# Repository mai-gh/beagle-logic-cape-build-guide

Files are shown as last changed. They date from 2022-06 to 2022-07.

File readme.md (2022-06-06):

# beagle-logic-cape-build-guide

## TL;DR:

upload `beaglelogic_cape_v1-1-gerbers.zip` to https://dirtypcbs.com/store/pcbs

## The Dilemma:

I found out about this project a little late, but it seems like it could be very useful, even if some things are a bit outdated.

I need a logic analyzer and i found this: https://sigrok.org/wiki/BeagleLogic

there are a few problems though. the beaglebone blacks gpios are only 3.3v tolerant, so this "cape" was made to allowing analyzing 5v circuits.
this board is not sold anywhere. ok so we can order a pcb and the components and buid it right? well finding gerbers to send to a pcb fabricator was tricky, they are not in the beagle logic repository. https://github.com/abhishek-kakkar/BeagleLogic (commit f9dab91ac01472fdafd758277ec8a4526c6267f5) (Jul 5, 2020)

however there is kicad design files which can be used to generate new gerbers. I described my process of how generated the gerbers with kicad 5.1.10-4 in [KiCad-Gerber-DirtyPCBs.md](https://github.com/mai-gh/beagle-logic-cape-build-guide/blob/main/KiCad-Gerber-DirtyPCBs.md)

## Components:

info comes from here: https://docs.google.com/spreadsheets/d/12azxrOXTphC75ShBOmVUEJG1oJav0N1jhAYYi9JiIA4/edit#gid=0

|Reference|Type |Qty|DigiKey|Mouser|Extra|
|---|---|---|---|---|-----|
|C1 |1uF 0603 X7R |1  |[490-10734-1-ND](https://www.digikey.com/en/products/result?keywords=490-10734-1-ND) |81-GRM188R71C105KE5D |
|C2 |0.1uF 0603 |1  |[490-1524-1-ND](https://www.digikey.com/en/products/result?keywords=490-1524-1-ND) |81-GRM39X104K25 |
|U1 |BeagleBone Stackable Cape Headers |2  |[1528-1365-ND](https://www.digikey.com/en/products/result?keywords=1528-1365-ND) || https://www.adafruit.com/products/706|
|U2 |SN74LVCH16T245DGGR |1  |[296-19568-1-ND](https://www.digikey.com/en/products/result?keywords=296-19568-1-ND) |595-SN74LVCH16T245GR |
|P1 |14x2 (28pin) right angled 2.54mm male pin strip |1  |[S2112EC-14-ND](https://www.digikey.com/en/products/result?keywords=S2112EC-14-ND) |(suggest alternative part here)|
|Q1 |BSS138 |1  |[BSS138CT-ND](https://www.digikey.com/en/products/result?keywords=BSS138CT-ND) |9845330 |
|R1 |0603, 100K |1  |[311-100KHRCT-ND](https://www.digikey.com/en/products/result?keywords=311-100KHRCT-ND)  |603-RC0603FR-07100KL |
|R14 |0603, 1K |1  |[311-1.00KHRCT-ND](https://www.digikey.com/en/products/result?keywords=311-1.00KHRCT-ND) |603-RC0603FR-071KL |
|R15 |0402, 0R (solder bridge in practice) |0  |[311-0.0JRCT-ND](https://www.digikey.com/en/products/result?keywords=311-0.0JRCT-ND) |603-RC0402JR-070RL |
|R8 |0603, 0R (not populated unless 14 channels are required) |0  |[311-0.0HRCT-ND](https://www.digikey.com/en/products/result?keywords=311-0.0HRCT-ND) |603-RC0603FR-070RL |
|R9 |0603, 0R (not populated unless 14 channels are required)  

## Cheaper Sources:

this table is for the cheapest prices to build 10 capes

|Ref|Link|Order Qty|
|---|----|---|
|C1 | https://lcsc.com/product-detail/Multilayer-Ceramic-Capacitors-MLCC-SMD-SMT_Taiyo-Yuden-EMK107B7105KA-T_C92759.html | 50  |
|C2 | https://lcsc.com/product-detail/Multilayer-Ceramic-Capacitors-MLCC-SMD-SMT_CCTC-TCC0603X7R104K500CT_C282519.html | 100 |
|U1 | https://www.aliexpress.com/item/3256803448359946.html | 2X20P 20PCS & 2X3P 20PCS |
|U2 | https://lcsc.com/product-detail/Receivers-Transceivers_Texas-Instruments-SN74LVCH16T245DGGR_C352975.html | 10  |
|P1 | https://lcsc.com/product-detail/Pin-Headers_HCTL-PZ254-2-14-W-8-5_C2894994.html | 10  |
|Q1 | https://lcsc.com/product-detail/MOSFETs_UMW-Youtai-Semiconductor-Co-Ltd-BSS138_C347484.html | 10  |
|R1 | https://lcsc.com/product-detail/Chip-Resistor-Surface-Mount_Walsin-Tech-Corp-WR06X1003FTL_C132374.html | 100 | 
|R14| https://lcsc.com/product-detail/Chip-Resistor-Surface-Mount_YAGEO-RC0603FR-071KL_C22548.html | 100 |

### Total Costs:

( includes shipping )

|Site|Description|Price|
|----|---|-----|
|dirtypcbs | 10x pcbs | $31.95 |
|aliexpress| stackable cape headers | $13.52 |
|lcsc | all other components | $22.98 |

**Total: $68.45**

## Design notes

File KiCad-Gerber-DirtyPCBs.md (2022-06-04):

# KiCad-Gerber-DirtyPCBs

### Original Document: https://github.com/VojislavM/KiCad-Gerber-Wiki

In this guide I will be using `kicad 5.1.10-4`

Documentation how to generate Gerber files from KiCad for PCB manufacturing at [dirtypcbs][DIRTY_PCB_LINK]. 

On this link, you can find all information about [dirtypcbs info][DIRTY_PCB_ABOUT_LINK] PCB manufacturing. 

There are several things need to be done before sending files to manufacture PCBs. Files are generated with KiCad EDA tool, and these are the steps to send your files to [dirtypcbs][DIRTY_PCB_LINK] and get your boards as you want.

When board file is finished:

1. Set the origin: Go to **Place** -> **Drill and Place offset** and then set the origin near the bottom left corner of the board. for this project i set the grid size to 1.0mm and chose:
- x: 114
- y: 130

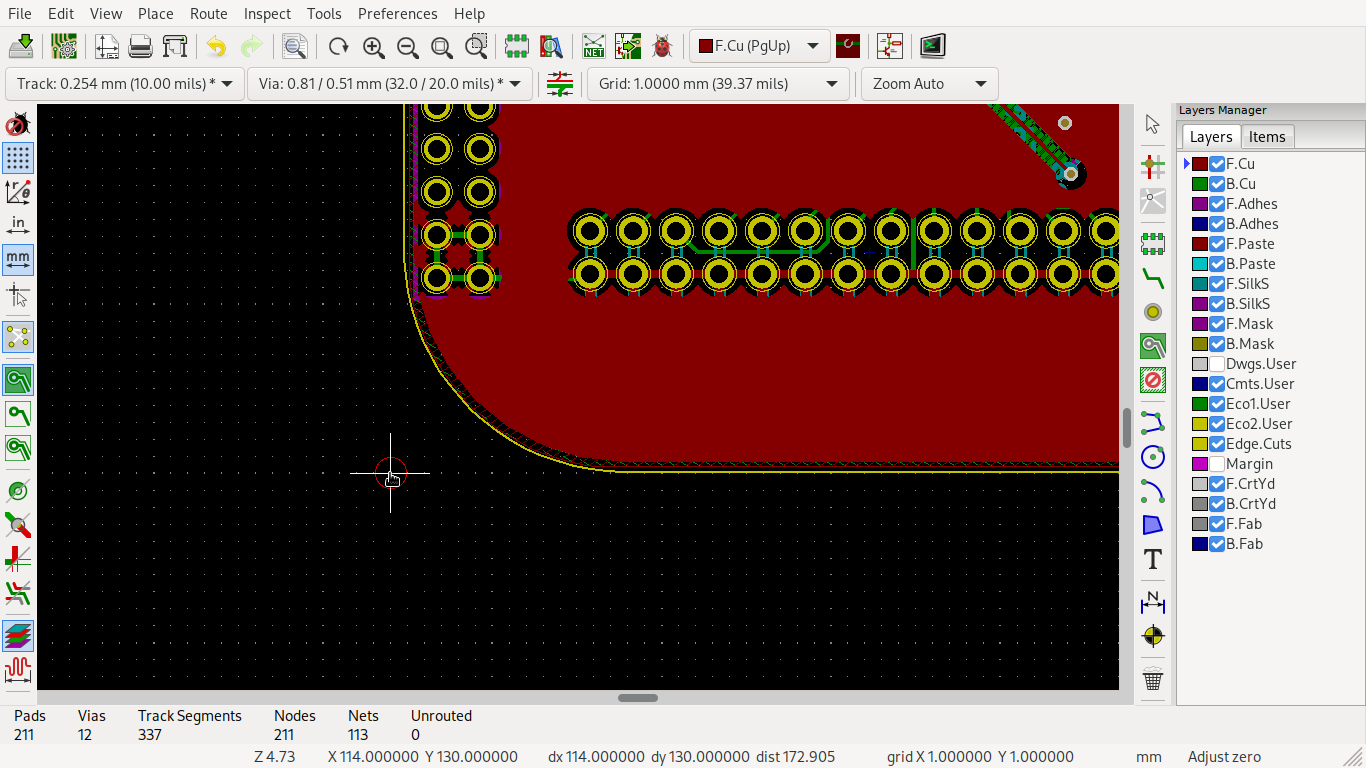
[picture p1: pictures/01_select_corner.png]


2. Generate Gerber files PDF: Go to **File** -> **Plot**. New Window will appear, like in picture 1.

make sure the following layers are selected:
- F.Cu
- B.Cu
- F.SilkS
- B.SilkS
- F.Mask
- B.Mask
- Edge.Cuts

 Click on **Plot** and it will generate Gerber files in PDF form so they could be checked. 

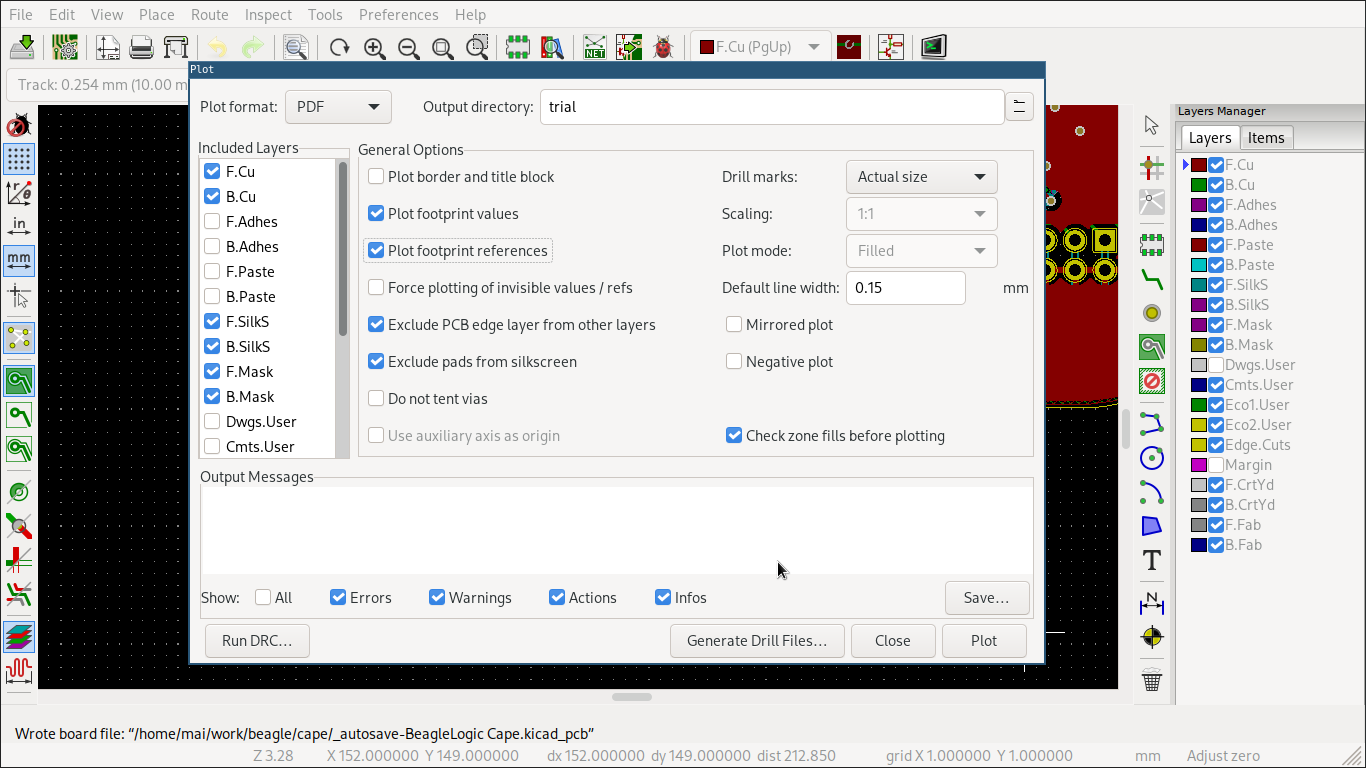
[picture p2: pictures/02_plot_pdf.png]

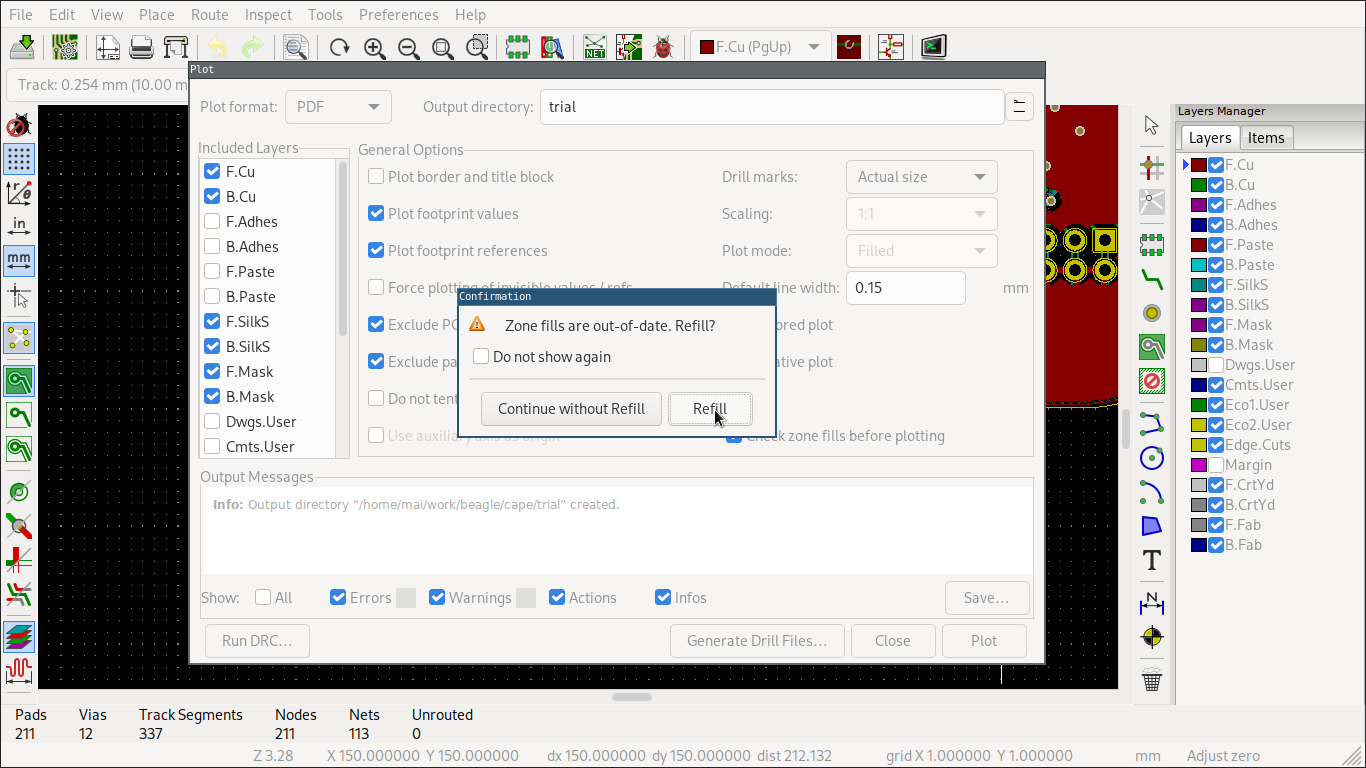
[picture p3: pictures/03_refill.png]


3. Generate Gerber files: In the same window click change the **Plot format** from PDF to **Gerber**, a window will change and it will look like in picture 2. Some additional boxes need to be checked and everything should be like in picture 2. Then click on **Plot** and Gerber files will be generated.

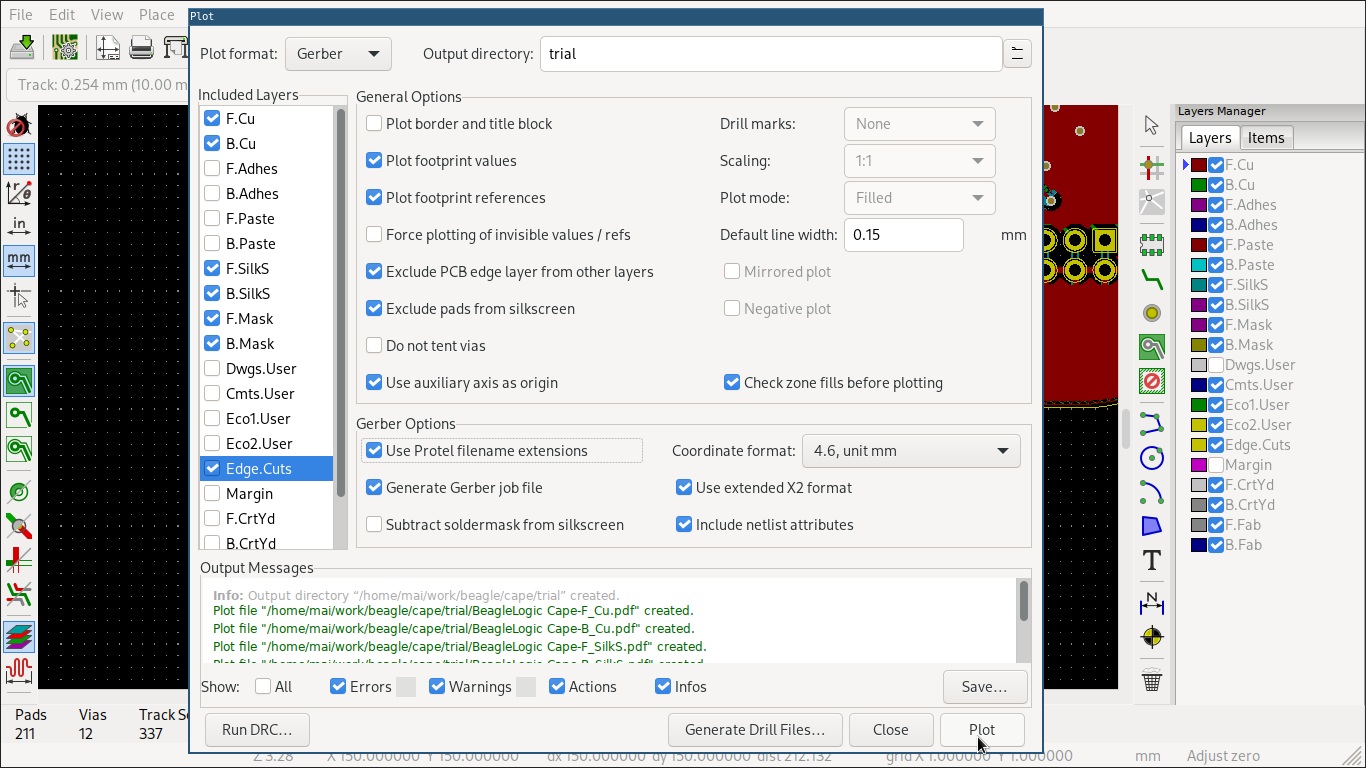
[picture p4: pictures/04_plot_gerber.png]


4. Generate Drill File: Next click on the **Generate Drill File** and the new window will appear, like in picture 3. Again everything should be like in picture 3. When everything is set click on **Drill File**, and Drill file will be generated. 
  
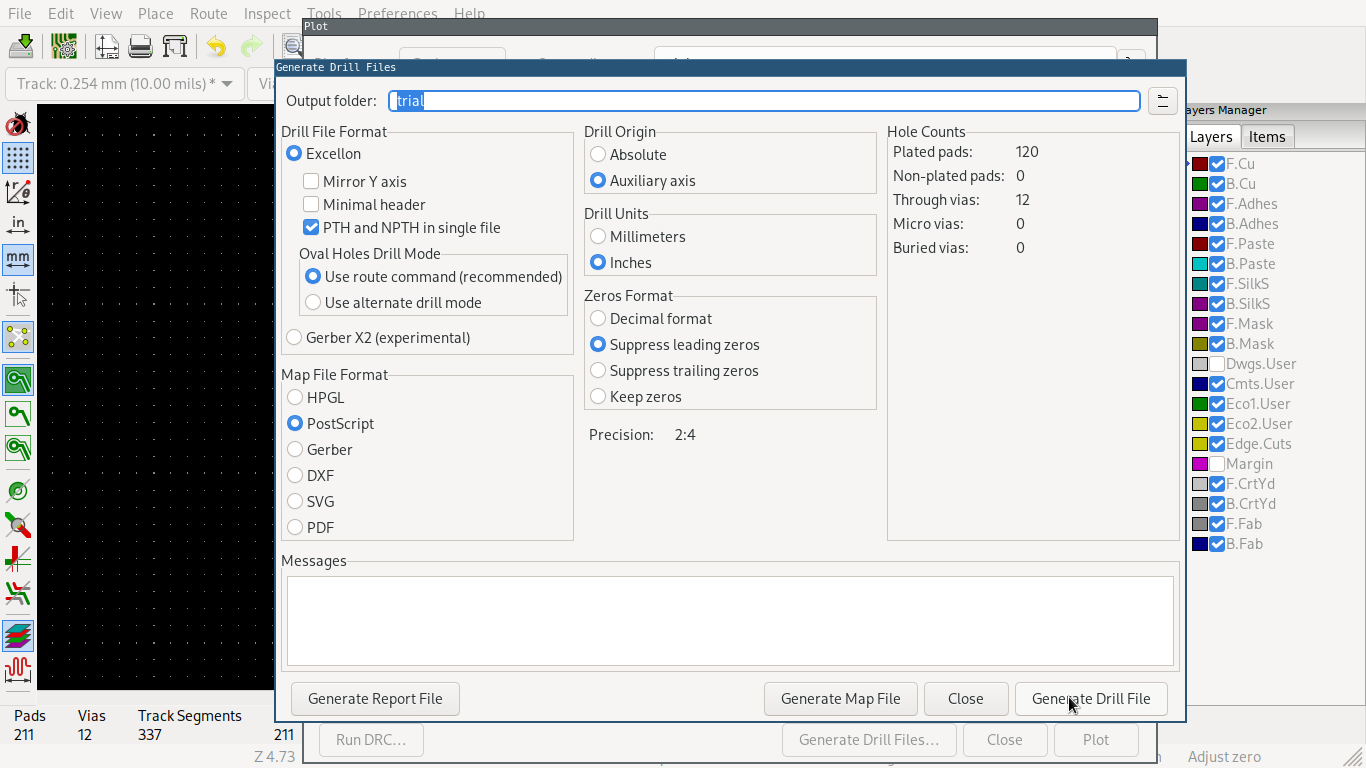
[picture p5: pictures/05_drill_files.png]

  **Note:** If there are plated and non plated holes in the design please check the "Merge PTH and NPTH holes into one file"

5. Change extensions: Extensions of files that contains Edge of the board and Drills needs to be changed. Go to project folder, than go to folder **/Gerber** and change extensions for Drill file from **.drl** to **.txt** and Edge (keepout) file from **.gm1** to **.gko**.

```
cd cape/trial
mkdir out
cp 'BeagleLogic Cape-F_SilkS.gto'    out/BeagleLogic_Cape-F_SilkS.gto
cp 'BeagleLogic Cape-F_Mask.gts'     out/BeagleLogic_Cape-F_Mask.gts
cp 'BeagleLogic Cape-F_Cu.gtl'       out/BeagleLogic_Cape-F_Cu.gtl
cp 'BeagleLogic Cape-B_Cu.gbl'       out/BeagleLogic_Cape-B_Cu.gbl
cp 'BeagleLogic Cape-B_Mask.gbs'     out/BeagleLogic_Cape-B_Mask.gbs
cp 'BeagleLogic Cape-B_SilkS.gbo'    out/BeagleLogic_Cape-B_SilkS.gbo
cp 'BeagleLogic Cape-Edge_Cuts.gm1'  out/BeagleLogic_Cape-Edge_Cuts.gko
cp 'BeagleLogic Cape.drl'            out/BeagleLogic_Cape-Drill.txt
cd out
zip beaglelogic_cape_v1-1-gerbers.zip *
```

After that everything is ready, just check your Gerber files in Gerber viewer and send them to manufacturing.

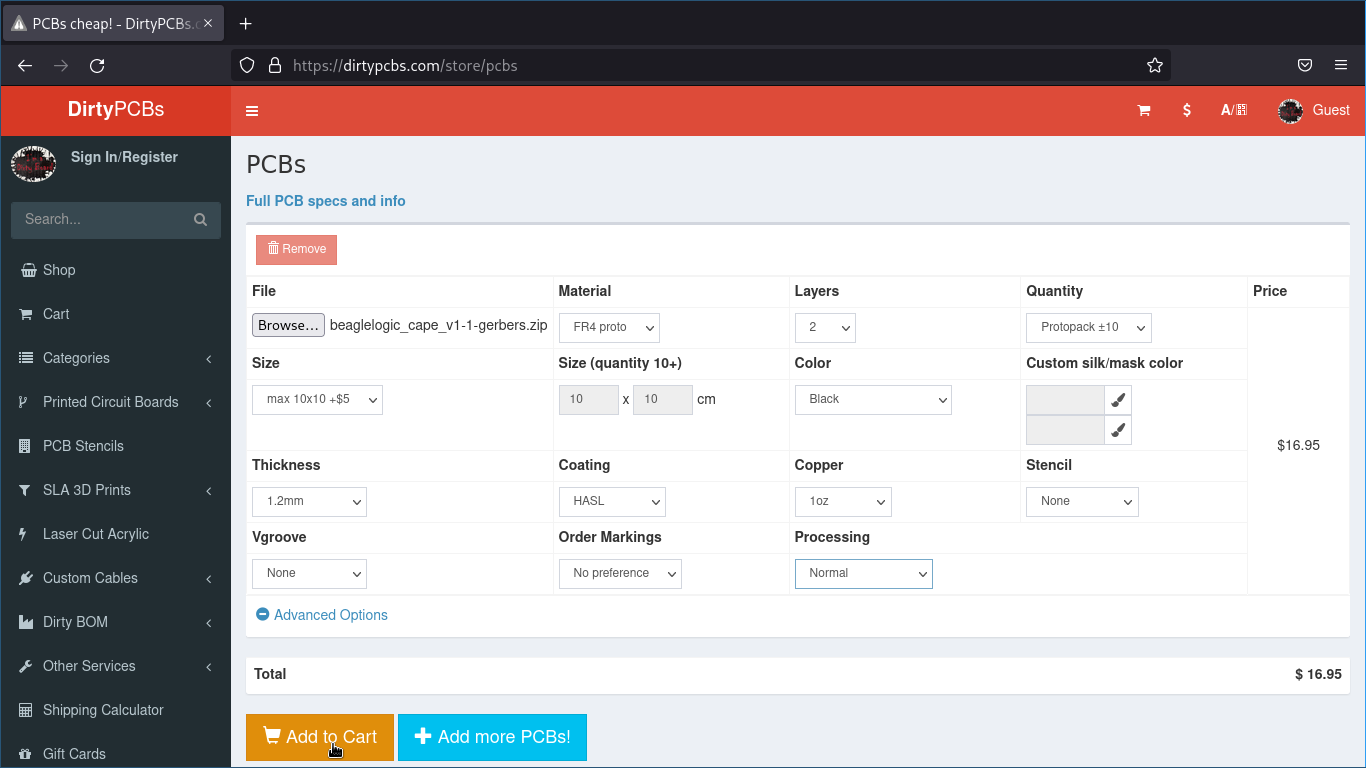
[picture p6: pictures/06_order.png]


**cross your finger and wait**

[//]: # (These are reference links used in the body)
[DIRTY_PCB_LINK]:<https://dirtypcbs.com/>
[DIRTY_PCB_ABOUT_LINK]:<https://dirtypcbs.com/store/pcbs/about>

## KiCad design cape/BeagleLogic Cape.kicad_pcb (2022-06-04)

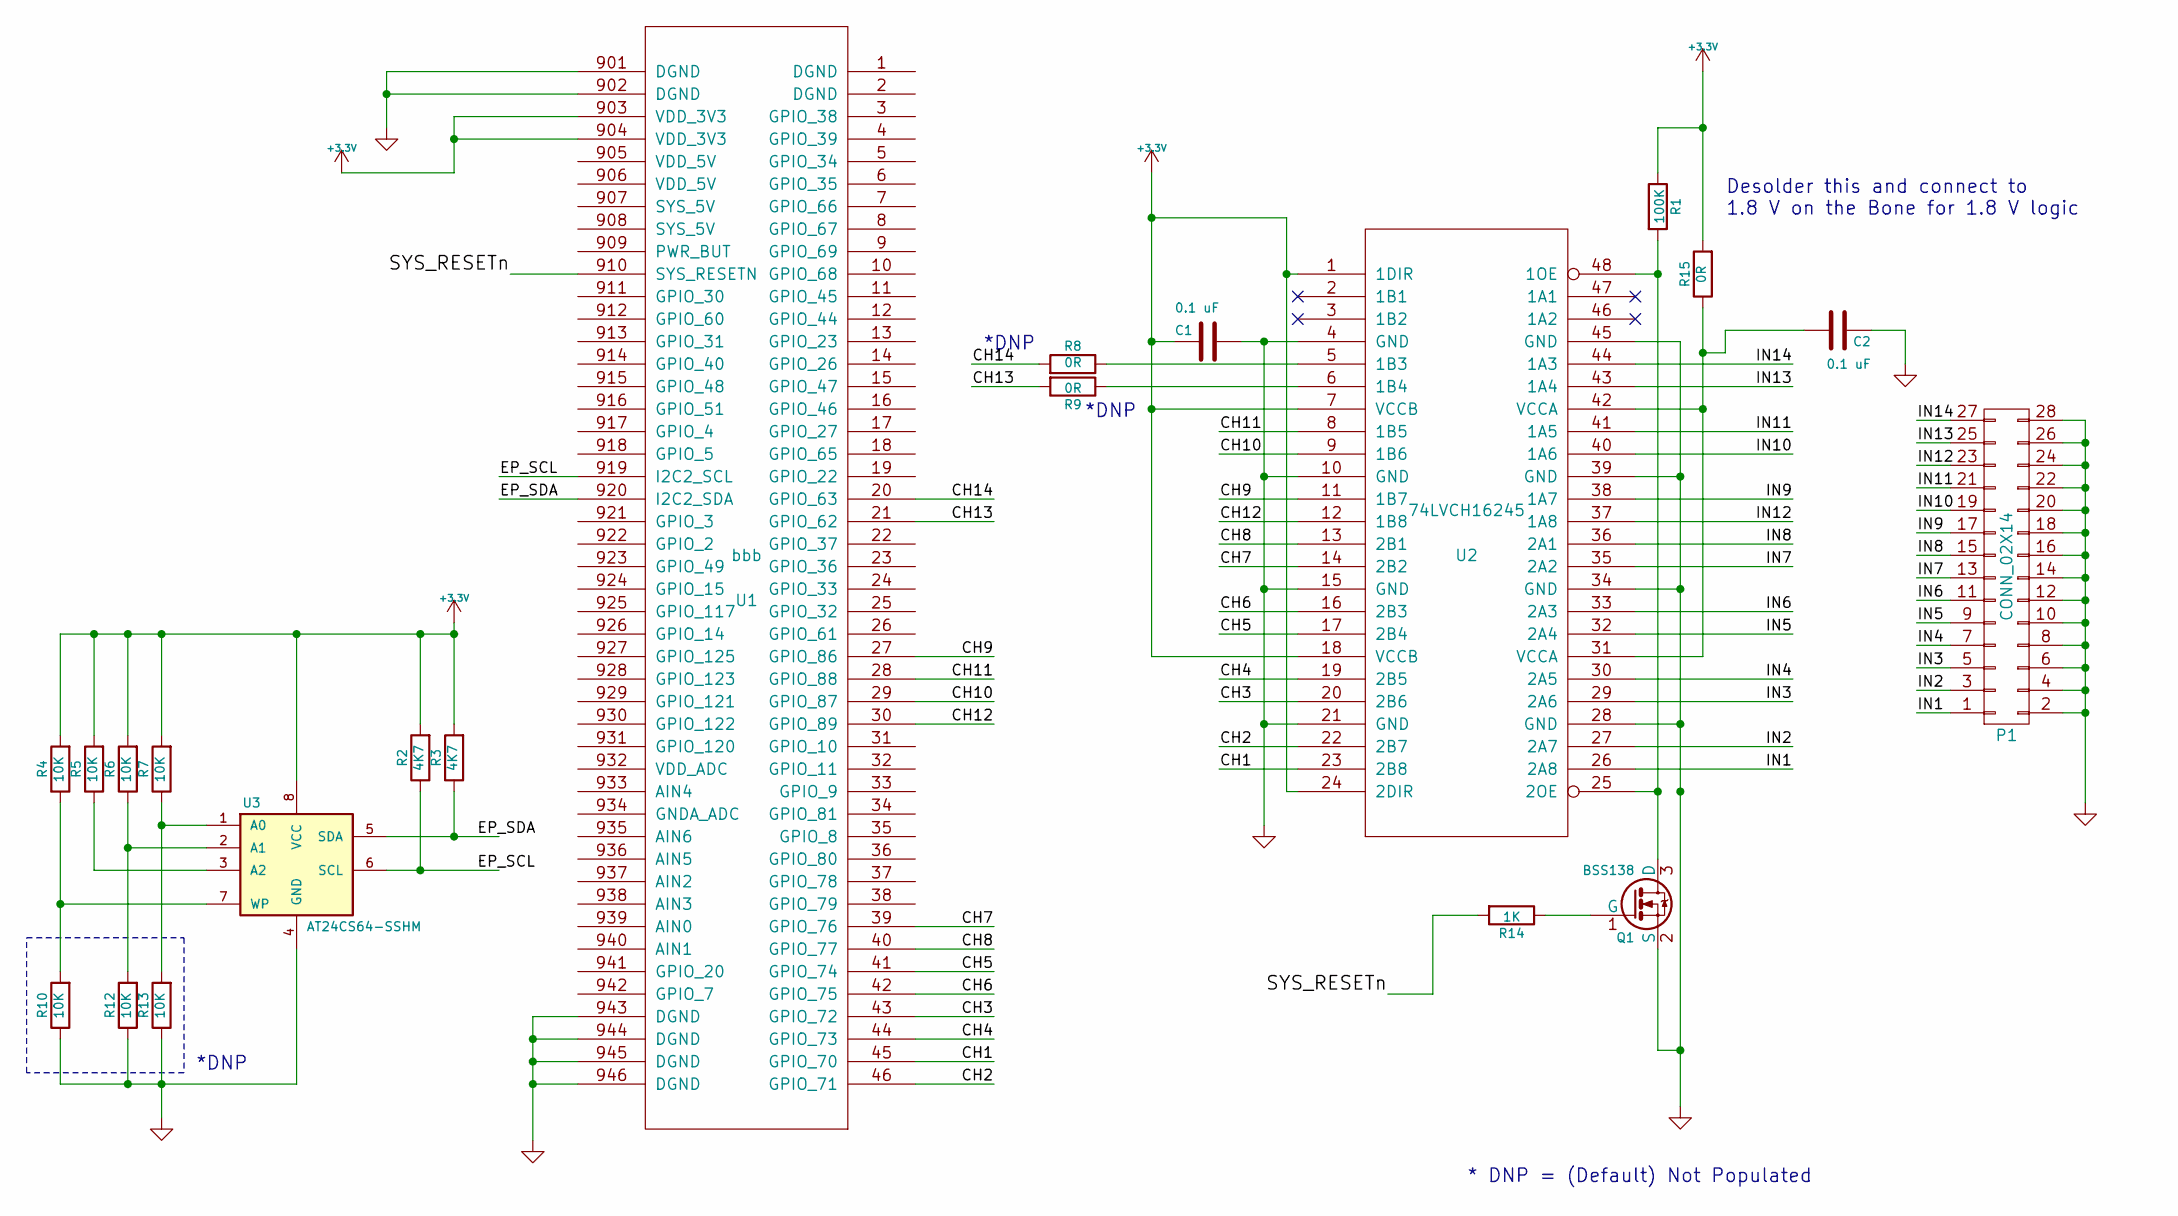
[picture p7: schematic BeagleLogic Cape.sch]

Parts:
C1, C2: 0.1 uF; SMD-0603
P1: CONN_02X14; Pin_Header_Angled_2x14
Q1: BSS138; SOT-23
R1: 100K; R_0603
R2, R3: 4K7; R_0603
R4, R5, R6, R7, R10, R12, R13: 10K; R_0603
R8, R9, R15: 0R; R_0603
R14: 1K; R_0603
U1: bbb; BBB
U2: 74LVCH16245; TSSOP-48_6.1x12.5mm_Pitch0.5mm
U3: AT24CS64-SSHM; SOIC-8-W

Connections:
+3.3V: C1.2, R1.1, R2.2, R3.2, R4.2, R5.2, R6.2, R7.2, R15.2, U1.903 (VDD_3V3), U1.904 (VDD_3V3), U2.1 (1DIR), U2.7 (VCCB), U2.18 (VCCB), U2.24 (2DIR), U3.8 (VCC)
/CH1: U1.45 (GPIO_70), U2.23 (2B8)
/CH2: U1.46 (GPIO_71), U2.22 (2B7)
/CH3: U1.43 (GPIO_72), U2.20 (2B6)
/CH4: U1.44 (GPIO_73), U2.19 (2B5)
/CH5: U1.41 (GPIO_74), U2.17 (2B4)
/CH6: U1.42 (GPIO_75), U2.16 (2B3)
/CH7: U1.39 (GPIO_76), U2.14 (2B2)
/CH8: U1.40 (GPIO_77), U2.13 (2B1)
/CH9: U1.27 (GPIO_86), U2.11 (1B7)
/CH10: U1.29 (GPIO_87), U2.9 (1B6)
/CH11: U1.28 (GPIO_88), U2.8 (1B5)
/CH12: U1.30 (GPIO_89), U2.12 (1B8)
/CH13: R9.2, U1.21 (GPIO_62)
/CH14: R8.2, U1.20 (GPIO_63)
/EP_SCL: R2.1, U1.919 (I2C2_SCL), U3.6 (SCL)
/EP_SDA: R3.1, U1.920 (I2C2_SDA), U3.5 (SDA)
/IN1: P1.1, U2.26 (2A8)
/IN2: P1.3, U2.27 (2A7)
/IN3: P1.5, U2.29 (2A6)
/IN4: P1.7, U2.30 (2A5)
/IN5: P1.9, U2.32 (2A4)
/IN6: P1.11, U2.33 (2A3)
/IN7: P1.13, U2.35 (2A2)
/IN8: P1.15, U2.36 (2A1)
/IN9: P1.17, U2.38 (1A7)
/IN10: P1.19, U2.40 (1A6)
/IN11: P1.21, U2.41 (1A5)
/IN12: P1.23, U2.37 (1A8)
/IN13: P1.25, U2.43 (1A4)
/IN14: P1.27, U2.44 (1A3)
/SYS_RESETn: R14.2, U1.910 (SYS_RESETN)
GND: C1.1, C2.2, P1.2, P1.4, P1.6, P1.8, P1.10, P1.12, P1.14, P1.16, P1.18, P1.20, P1.22, P1.24, P1.26, P1.28, Q1.2 (S), R10.1, R12.1, R13.1, U1.901 (DGND), U1.902 (DGND), U1.943 (DGND), U1.944 (DGND), U1.945 (DGND), U1.946 (DGND), U2.4 (GND), U2.10 (GND), U2.15 (GND), U2.21 (GND), U2.28 (GND), U2.34 (GND), U2.39 (GND), U2.45 (GND), U3.4 (GND)
unnamed: C2.1, R15.1, U2.31 (VCCA), U2.42 (VCCA)
unnamed: Q1.1 (G), R14.1
unnamed: Q1.3 (D), R1.2, U2.25 (2OE), U2.48 (1OE)
unnamed: R5.1, U3.3 (A2)
unnamed: R8.1, U2.5 (1B3)
unnamed: R9.1, U2.6 (1B4)
unnamed: R4.1, R10.2, U3.7 (WP)
unnamed: R6.1, R12.2, U3.2 (A1)
unnamed: R7.1, R13.2, U3.1 (A0)

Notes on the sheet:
*DNP
* DNP = (Default) Not Populated
Desolder this and connect to 1.8 V on the Bone for 1.8 V logic

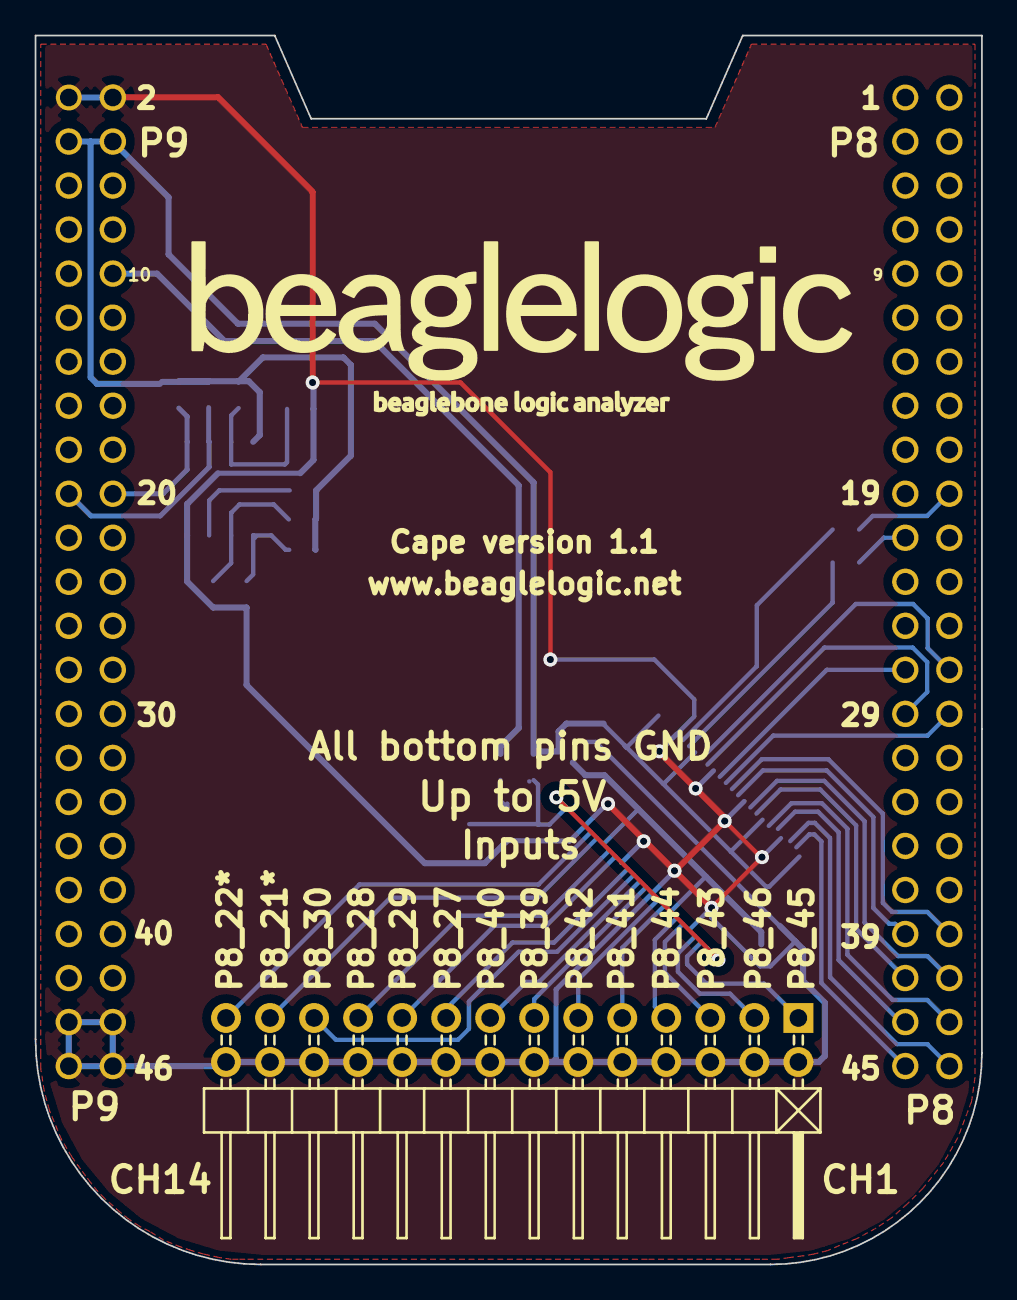
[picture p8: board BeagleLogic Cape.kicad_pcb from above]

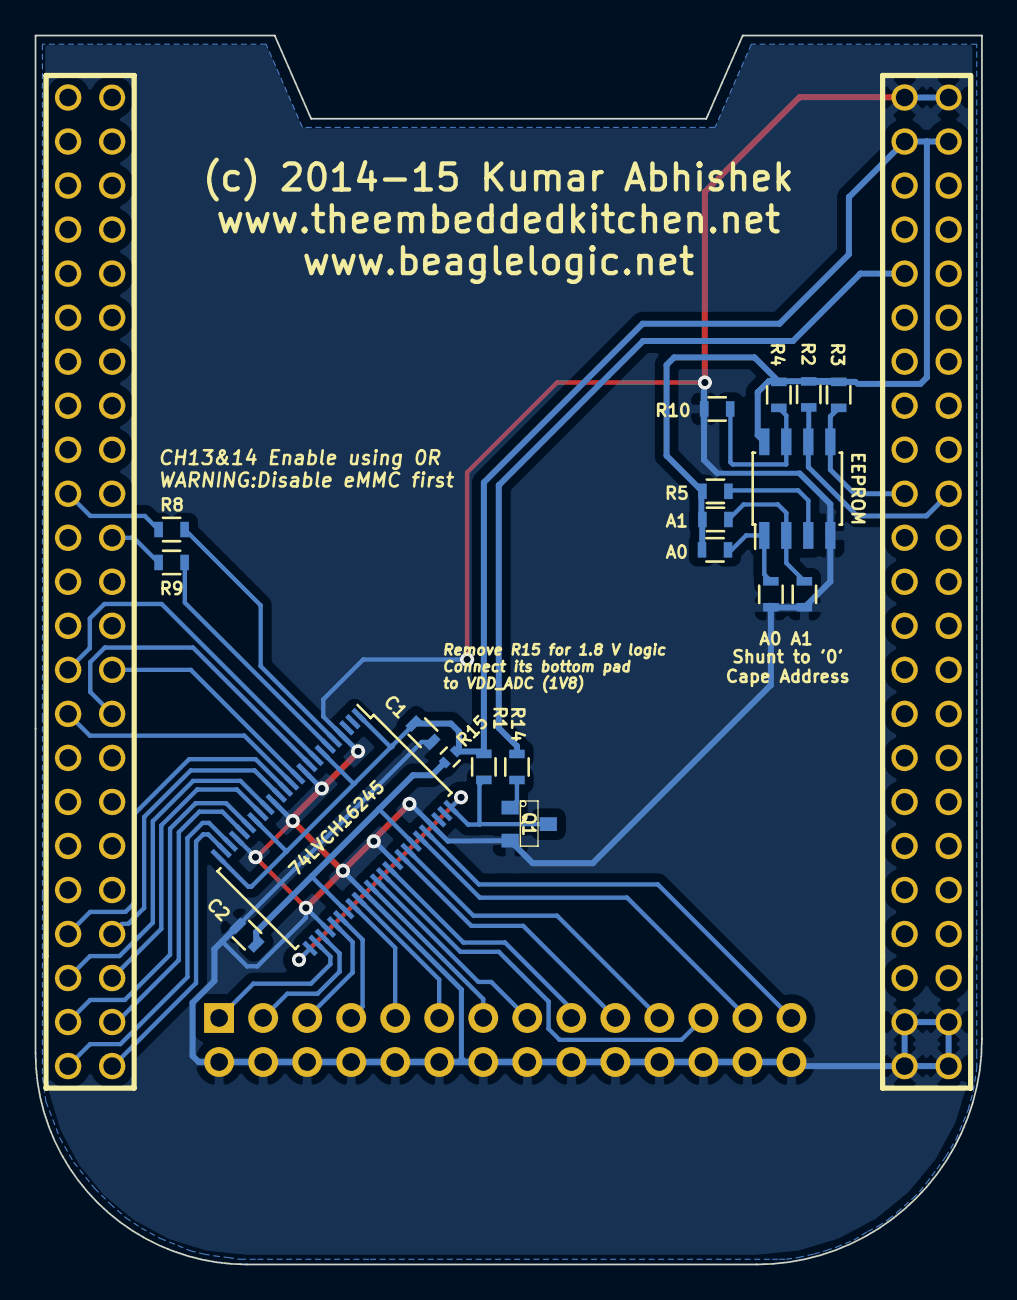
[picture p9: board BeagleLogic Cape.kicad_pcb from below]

Board: 2 copper layers, 54.6 x 70.9 mm, 21 parts (20 on the bottom side), 42 nets.

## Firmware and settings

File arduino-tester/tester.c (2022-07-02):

/*
                                      +-----+
         +----[PWR]-------------------| USB |--+
         |                            +-----+  |
         |         GND/RST2  [ ][ ]            |
         |       MOSI2/SCK2  [ ][ ]  A5/SCL[ ] |   C5
         |          5V/MISO2 [ ][ ]  A4/SDA[ ] |   C4
         |                             AREF[ ] |
         |                              GND[ ] |
         | [ ]N/C                    SCK/13[ ] |   B5
         | [ ]IOREF                 MISO/12[ ] |   .
         | [ ]RST                   MOSI/11[ ]~|   .
         | [ ]3V3    +---+               10[ ]~|   .
         | [ ]5v    -| A |-               9[ ]~|   .
         | [ ]GND   -| R |-               8[ ] |   B0
         | [ ]GND   -| D |-                    |
         | [ ]Vin   -| U |-               7[ ] |   D7
         |          -| I |-               6[ ]~|   .
         | [ ]A0    -| N |-               5[ ]~|   .
         | [ ]A1    -| O |-               4[ ] |   .
         | [ ]A2     +---+           INT1/3[ ]~|   .
         | [ ]A3                     INT0/2[ ] |   .
         | [ ]A4/SDA  RST SCK MISO     TX>1[ ] |   .
         | [ ]A5/SCL  [ ] [ ] [ ]      RX<0[ ] |   D0
         |            [ ] [ ] [ ]              |
         |  UNO_R3    GND MOSI 5V  ____________/
          \_______________________/
*/



#define F_CPU 16000000UL
#include <avr/io.h>
#include <util/delay.h>

volatile unsigned char count __attribute__((section(".noinit"))); // Not cleared on RESET

void set_pin_high(volatile uint8_t *PORT, uint8_t PIN) { *PORT |= (1 << PIN); }
void set_pin_low(volatile uint8_t *PORT, uint8_t PIN) { *PORT &= ~(1 << PIN); }

void set_all_output() {
  DDRD |= (1 << PD0); // CH01
  DDRD |= (1 << PD1); // CH02
  DDRD |= (1 << PD2); // CH03
  DDRD |= (1 << PD3); // CH04
  DDRD |= (1 << PD4); // CH05
  DDRD |= (1 << PD5); // CH06
  DDRD |= (1 << PD6); // CH07
  DDRD |= (1 << PD7); // CH08
  DDRB |= (1 << PB0); // CH09
  DDRB |= (1 << PB1); // CH10
  DDRB |= (1 << PB2); // CH11
  DDRB |= (1 << PB3); // CH12
}


void set_all_low() {
  PORTD &= ~(1 << PD0);
  PORTD &= ~(1 << PD1);
  PORTD &= ~(1 << PD2);
  PORTD &= ~(1 << PD3);
  PORTD &= ~(1 << PD4);
  PORTD &= ~(1 << PD5);
  PORTD &= ~(1 << PD6);
  PORTD &= ~(1 << PD7);
  PORTB &= ~(1 << PB0);
  PORTB &= ~(1 << PB1);
  PORTB &= ~(1 << PB2);
  PORTB &= ~(1 << PB3);
}





void main()
{

  set_all_output();
  set_all_low();

  MCUSR=0;
  DDRB |= (1 << PB5); // LED output

  if (count >= 13) {
    count = 0;
  }

  switch (count) {
    case 1:
      set_pin_high(&PORTD, PD0);
      break;
    case 2:
      set_pin_high(&PORTD, PD1);
      break;
    case 3:
      set_pin_high(&PORTD, PD2);
      break;
    case 4:
      set_pin_high(&PORTD, PD3);
      break;
    case 5:
      set_pin_high(&PORTD, PD4);
      break;
    case 6:
      set_pin_high(&PORTD, PD5);
      break;
    case 7:
      set_pin_high(&PORTD, PD6);
      break;
    case 8:
      set_pin_high(&PORTD, PD7);
      break;
    case 9:
      set_pin_high(&PORTB, PB0);
      break;
    case 10:
      set_pin_high(&PORTB, PB1);
      break;
    case 11:
      set_pin_high(&PORTB, PB2);
      break;
    case 12:
      set_pin_high(&PORTB, PB3);
      break;

  }
  count++;
  while (1) {}

}

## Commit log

2022-06-06 BOM order updates
2022-07-02 added arduino tester code

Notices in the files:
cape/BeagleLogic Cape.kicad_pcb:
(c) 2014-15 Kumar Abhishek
